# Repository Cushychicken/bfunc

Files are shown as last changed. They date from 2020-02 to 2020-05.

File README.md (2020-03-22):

# bfunc - An open source, breadboard friendly function generator

These are the source files for bfunc, a function generator I've been desiging, building, and programming in my spare time. 

The fastest way to understand what's going on here is to read [the design document](http://cushychicken.github.io/bfunc-design-doc/). That should give you a good top-level understanding of this project. If it doesn't, there's a Contact link on my blog. I encourage you to let me know if there's something you don't understand, or is otherwise unclear!

## Project Structure

All hardware files can be found in the `hardware/` directory. All hardware design was done using KiCAD. 

Software is broken into two directories: 

* `sw_embedded/` for all the code running on the bFunc board, and
* `sw_desktop/`, which contains the Python app for the GUI. 

The sw_embedded directory contains two subfolders:

* `stm32_cube_bfunc/` contains all the software used for building the prototype, which I made out of a STM32 BluePill board and a SparkFun Minigen Pro shield. 
* `bfunc_rev1/` contains all the software used in the first board revision. 

## How can I contribute? 

I'm so glad you asked! Check out the [Call for Users](http://cushychicken.github.io/bfunc-call-for-users/) page on my blog. That will outline the next steps for getting a board, and getting yourself set up to work on it. 

After all that, if you _still_ can't get enough bFunc in your life - I've been keeping weekly project journals on my blog in addition to the design document. Here is a [link to the first one](http://cushychicken.github.io/bfunc-weekone-log/) to get you started.

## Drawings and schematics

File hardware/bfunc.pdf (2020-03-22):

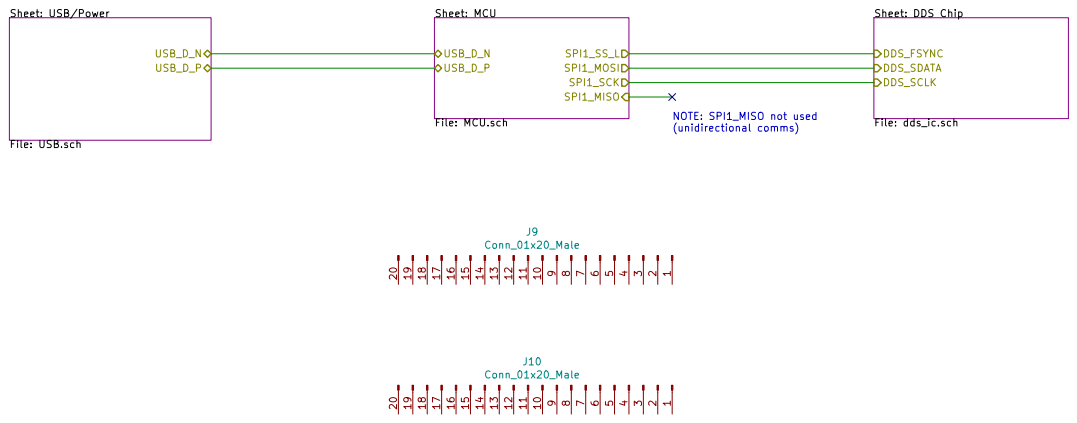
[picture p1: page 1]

Sheet: DDS Chip File: dds_ic.sch DDS_FSYNC

Id: 1/4 Title: File: bfunc.sch Sheet: /

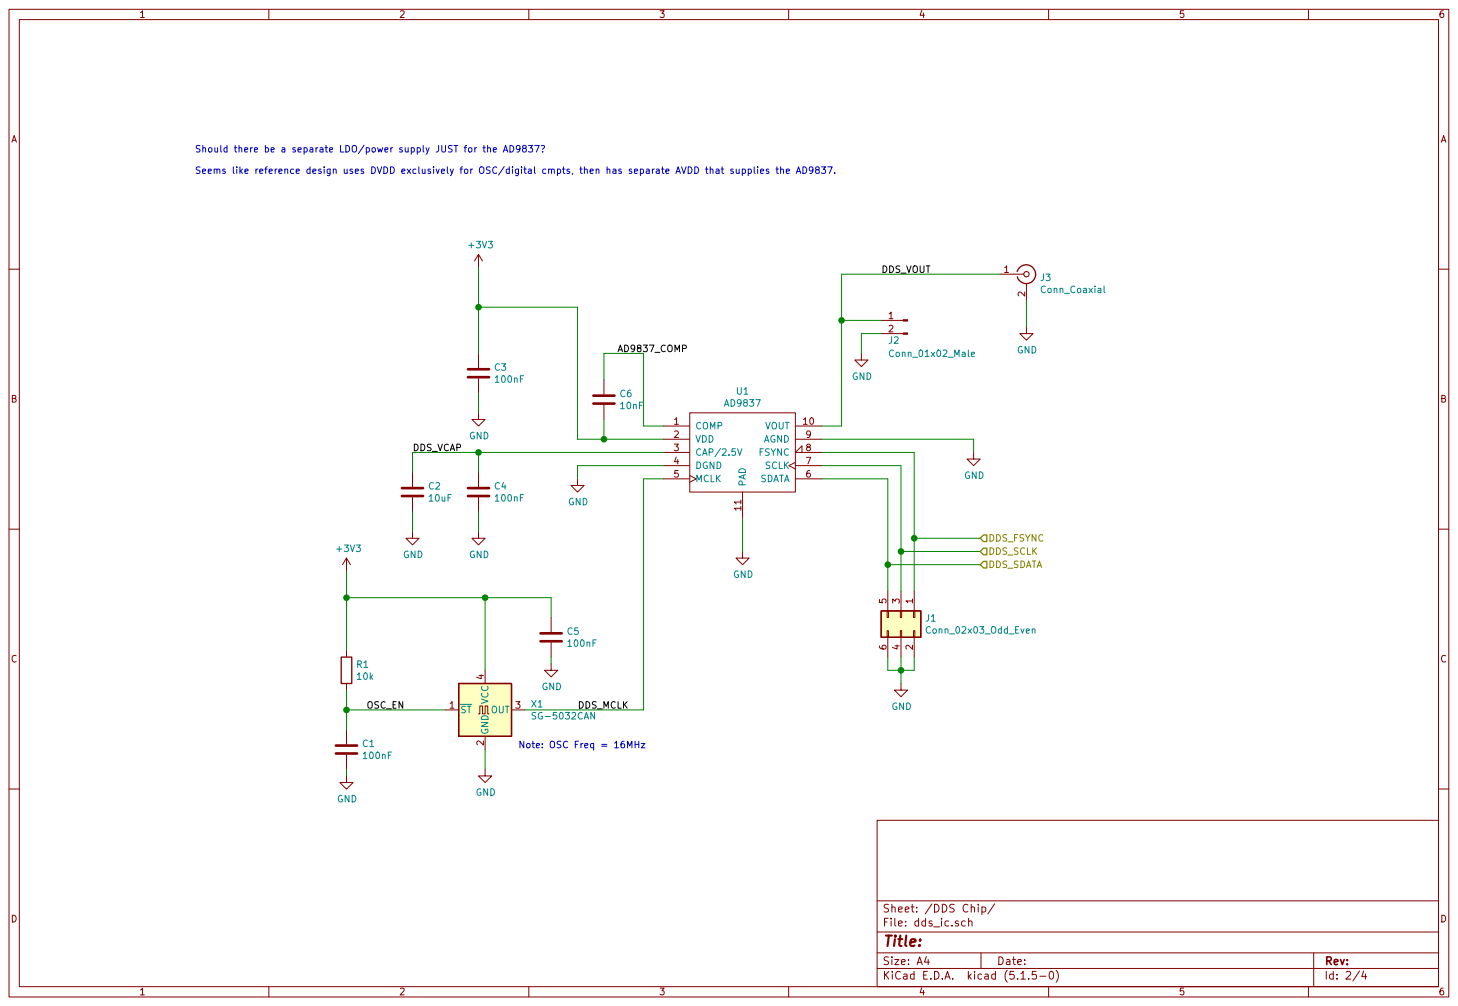
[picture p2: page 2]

Should there be a separate LDO/power supply JUST for the AD9837?

Seems like reference design uses DVDD exclusively for OSC/digital cmpts, then has separate AVDD that supplies the AD9837.

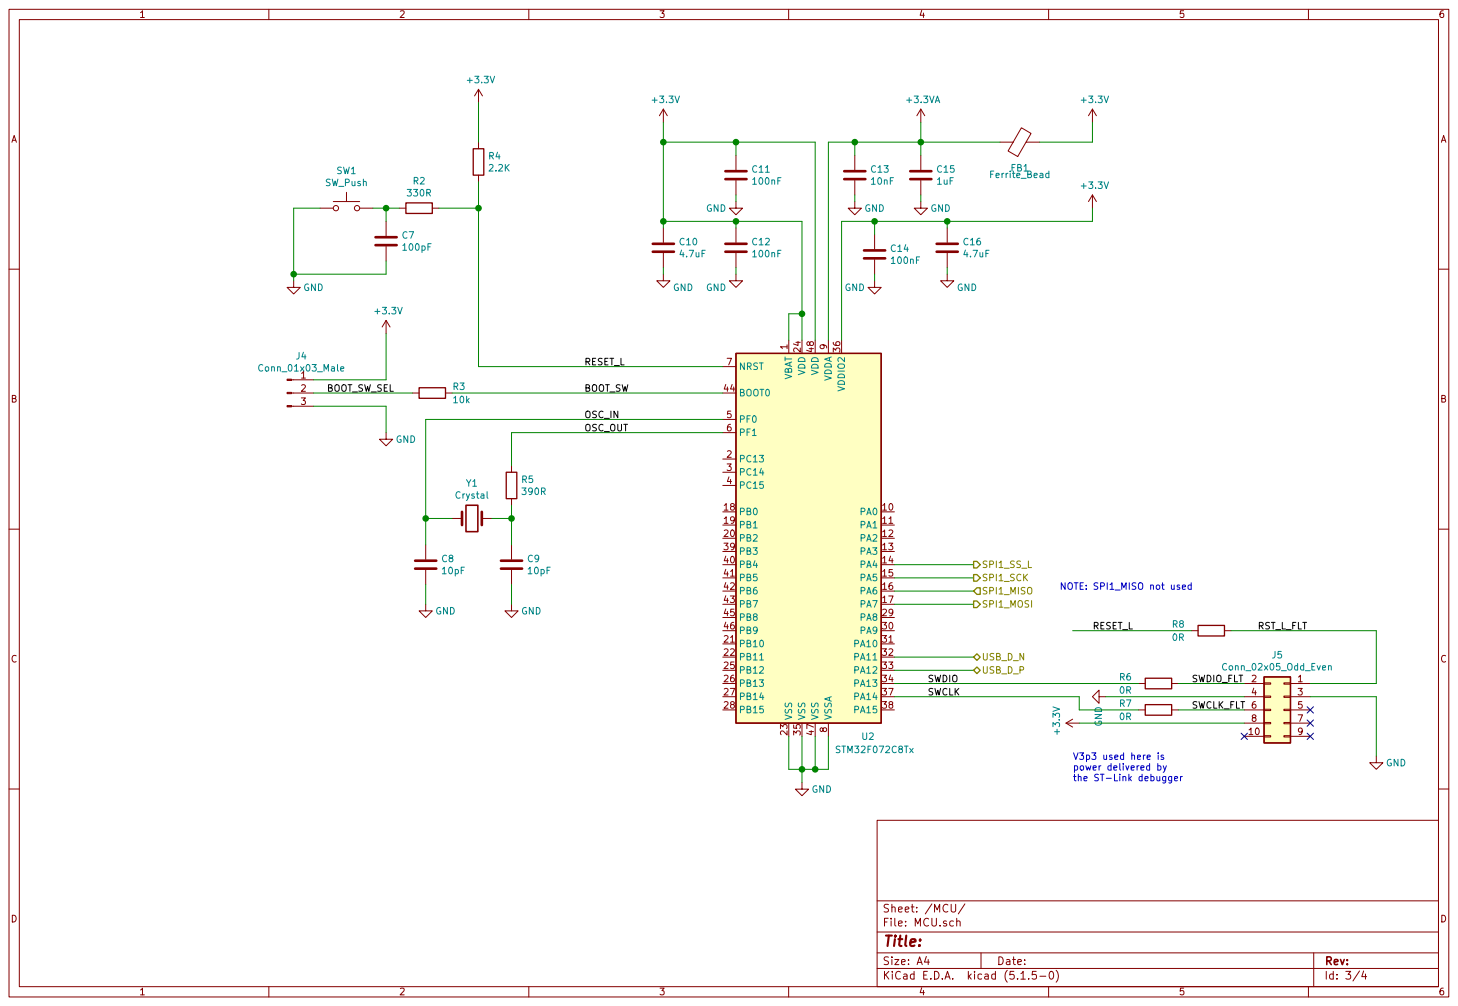
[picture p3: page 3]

1 PA0 10 PA1 11 PA2 12 PA3 13 PA4 14 PA5 15 PA6 16 PA7 17 PB0 18 PB1 19 PC13 2 PB2 20 PB10 21 PB11 22 VSS 23 VDD 24 PB12 25 PB13 26 PB14 27 PB15 28 PA8 29 PC14 3 PA9 30 PA10 31 PA11 32 PA12 33 PA13 34 VSS 35 VDDIO2 36 PA14 37 PA15 38 PB3 39 PC15 4 PB4 40 PB5 41 PB6 42 PB7 43 BOOT0 44 PB8 45 PB9 46 VSS 47 VDD 48 PF0 5 PF1 6 NRST 7 VSSA

power delivered by
the ST-Link debugger

Id: 3/4 Title: File: MCU.sch Sheet: /MCU/

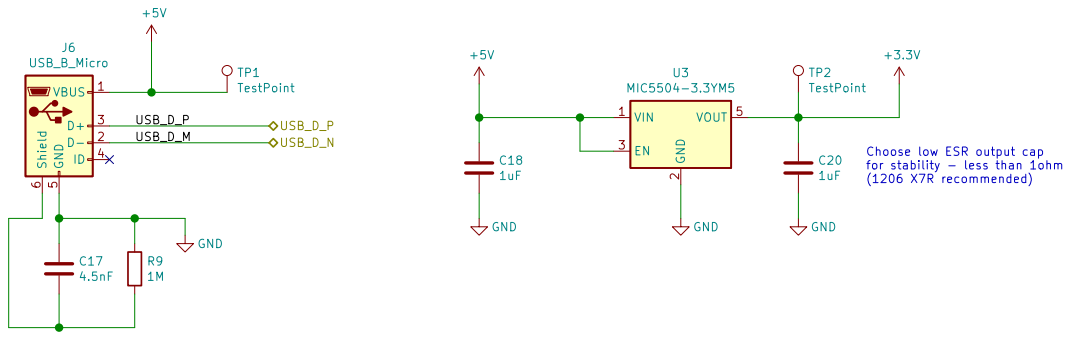
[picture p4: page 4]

2 EN 3 VOUT 5 U3 MIC5504-3.3YM5 TP2 TestPoint TP1 TestPoint GND

Choose low ESR output cap
for stability - less than 1ohm
(1206 X7R recommended)

Id: 4/4 Title: File: USB.sch Sheet: /USB/Power/

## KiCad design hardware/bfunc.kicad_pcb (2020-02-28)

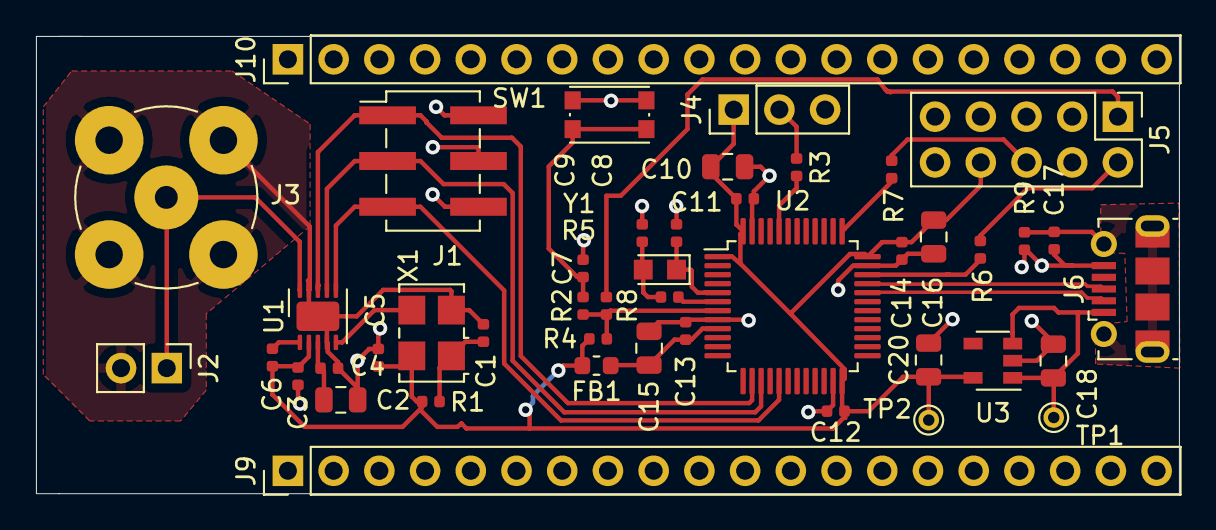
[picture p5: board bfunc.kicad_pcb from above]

Board: 2 copper layers, 63.5 x 25.4 mm, 45 parts (0 on the bottom side), 27 nets.

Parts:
C1, C3, C4, C5, C11, C12, C14: 100nF; C_0402_1005Metric
C2: 10uF; C_0805_2012Metric
C6, C13: 10nF; C_0402_1005Metric
C7: 100pF; C_0402_1005Metric
C8, C9: 10pF; C_0402_1005Metric
C10, C16: 4.7uF; C_0805_2012Metric
C15, C18, C20: 1uF; C_0805_2012Metric
C17: 4.5nF; C_0402_1005Metric
FB1: Ferrite_Bead; L_0603_1608Metric
J1: Conn_02x03_Odd_Even; PinHeader_2x03_P2.54mm_Vertical_SMD
J2: Conn_01x02_Male; PinHeader_1x02_P2.54mm_Vertical
J3: Conn_Coaxial; BNC_TEConnectivity_1478204_Vertical
J4: Conn_01x03_Male; PinHeader_1x03_P2.54mm_Vertical
J5: Conn_02x05_Odd_Even; PinHeader_2x05_P2.54mm_Vertical
J6: USB_B_Micro; USB_Micro-B_Molex-105017-0001
J9, J10: Conn_01x20_Male; PinHeader_1x20_P2.54mm_Vertical
R1, R3: 10k; R_0402_1005Metric
R2: 330R; R_0402_1005Metric
R4: 2.2K; R_0402_1005Metric
R5: 390R; R_0402_1005Metric
R6, R7, R8: 0R; R_0402_1005Metric
R9: 1M; R_0402_1005Metric
SW1: SW_Push; SW_Push_1P1T_NO_CK_KMR2
TP1, TP2: TestPoint; PINTST
U1: AD9837; LFCSP-WD-10-1EP_3x3mm_P0.5mm_EP1.64x2.38mm
U2: STM32F072C8Tx; LQFP-48_7x7mm_P0.5mm
U3: MIC5504-3.3YM5; SOT-23-5
X1: SG-5032CAN; Oscillator_SMD_SeikoEpson_SG8002LB-4pin_5.0x3.2mm
Y1: Crystal; Crystal_SMD_TXC_9HT11-2pin_2.0x1.2mm_HandSoldering

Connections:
+3.3VA: C13.1, C15.1, FB1.1, U2.9
+3V3: C3.1, C5.1, C6.2, C10.1, C11.1, C12.1, C14.1, C16.1, C20.1, FB1.2, J4.1, J5.8, R1.1, R4.1, TP2.1, U1.2, U2.1, U2.24, U2.36, U2.48, U3.5, X1.4
+5V: C18.1, J6.1, TP1.1, U3.1, U3.3
/DDS Chip/AD9837_COMP: C6.1, U1.1
/DDS Chip/DDS_FSYNC: J1.1, U1.8, U2.14
/DDS Chip/DDS_MCLK: U1.5, X1.3
/DDS Chip/DDS_SCLK: J1.3, U1.7, U2.15
/DDS Chip/DDS_SDATA: J1.5, U1.6, U2.17
/DDS Chip/DDS_VCAP: C2.1, C4.1, U1.3
/DDS Chip/DDS_VOUT: J2.1, J3.1, U1.10
/DDS Chip/OSC_EN: C1.1, R1.2, X1.1
/MCU/BOOT_SW: R3.1, U2.44
/MCU/BOOT_SW_SEL: J4.2, R3.2
/MCU/OSC_IN: C8.1, U2.5, Y1.1
/MCU/OSC_OUT: R5.1, U2.6
/MCU/RESET_L: R2.1, R4.2, R8.2, U2.7
/MCU/RST_L_FLT: J5.1, R8.1
/MCU/SWCLK: R7.2, U2.37
/MCU/SWCLK_FLT: J5.6, R7.1
/MCU/SWDIO: R6.2, U2.34
/MCU/SWDIO_FLT: J5.2, R6.1
/MCU/USB_D_N: J6.2, U2.32
/MCU/USB_D_P: J6.3, U2.33
GND: C1.2, C2.2, C3.2, C4.2, C5.2, C7.2, C8.2, C9.2, C10.2, C11.2, C12.2, C13.2, C14.2, C15.2, C16.2, C17.1, C18.2, C20.2, J1.2, J1.4, J1.6, J2.2, J3.2, J4.3, J5.3, J5.4, J6.5, R9.1, SW1.1, U1.4, U1.9, U1.11, U2.8, U2.23, U2.35, U2.47, U3.2, X1.2
unnamed: C7.1, R2.2, SW1.2
unnamed: C9.1, R5.2, Y1.2
unnamed: C17.2, J6.6, R9.2

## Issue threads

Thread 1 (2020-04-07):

Waveform out of sync over 2.3mhz.

whinis, 2020-04-07:
Once the frequency goes above 2.3mhz or there about the signal appear to lose sync for all wave forms. The frequency appears to be close to the set value up to 5mhz but  it fails  to stay consistent. Below are 2 captures from my oscilloscope of a Square wave and Sine wave both at 3mhz
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

Cushychicken, 2020-04-07:
@whinis have you tried increasing the vertical scale of your oscilloscope? I noticed a similar problem with my Rigol not triggering properly at lower amplitudes. Increasing the vertical signal scale resolved that.

I see an issue with the sine wave, but a different one - at 2.3MHz (and to a lesser extent at 1MHz) you're seeing extra harmonic junk from the DDS DAC. Instead of being a nice smooth sine wave, you get a bunch of nasty capacitive transitions. Will need to design a filter for the next board rev to improve this.

I see the issue you describe with the square wave. That's junk. Need to dig into that.

whinis, 2020-04-07:
Yes, I have attempted to increase the vertical scale and see the same stuff. Its likely the harmonics and them switching forms back and forth that's causing this issue because as you can sort of see there is 3 nodes in the sine wave.

whinis, 2020-04-08:
Here is an update. I tried it with both a 100nf capacitor as suggested in the datasheet as well as 100pf. the 100pf helped a bit but there is other errors happening. Here it is now at 5mhz, both an average as well as single shot. The 100nf turned the square into a triangle and ruined both sine and triangle waves.
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

Cushychicken, 2020-04-09:
Interesting. Just to confirm - you're placing this capacitor at the output, from the VOUT pin to AGND? I haven't seen any references to needing a 100nF cap at the VOUT pin in the datasheet. There is the test circuit suggestion of adding 20pF at the output pin on page 9 of the datasheet:

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

This is also consistent with the AD9834, which suggests including a 20pF cap at the current output of that chip to help reduce clock feedthru. (The AD9837 integrates a 200 ohm termination resistor onto the die - these are external components required by the AD9834.)

In any case - what I think we're seeing here is harmonic overtones as a result of operating closer to the DDS chip's oscillator frequency. The on-board oscillator is running at 16MHz - it's definitely not going to do anything close to sinusoidal reconstruction as you get closer to 8MHz.

A higher order filter design is needed, and that's probably not something we'll be able to add to this PCB. Might be a good job for a separate filter PCB, though. I've linked this circuit note from Analog Devices on the AD9834, which is a part in the same family as the AD9837, which includes a little design brief for a 7th order elliptic lowpass filter at the output of the generator. You can see the spectrum plots on page 3 that shows the difference in harmonic content between the raw IOUT terminated output (equivalent to VOUT in our case) and the harmonic content at the output of the elliptic filter.

https://www.analog.com/media/en/reference-design-documentation/reference-designs/CN0304.pdf

whinis, 2020-04-09:
So, I found that cap advice on their evaluation board at https://www.analog.com/media/en/technical-documentation/user-guides/UG-269.pdf
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

However yes, this is a 0603 cap sitting between the VOUT and AGND pins directly on the other side of the board from the BNC. its the perfect distance for a 0603

Cushychicken, 2020-04-09:
Hm. I wonder if that was a placeholder footprint. (200Ω || 100nF) yields a -3dB frequency of about 8kHz.

whinis, 2020-04-09:
If the picture on your website is correct you may be onto something as that pad looks unpopulated on the image.
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

Cushychicken, 2020-04-11:
@whinis have you ever tried your hand at filter design before? I plugged in the parameters for a 7th order elliptic lowpass filter into the [rf-tools filter calculator website](https://rf-tools.com/lc-filter/) and got this result:

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

I don't have any of the components for this on hand - wondering if you happen to have any of the required inductor or cap values.

whinis, 2020-04-11:
I don't have the inductors on hand but every everything else. Also need to wait until the end of the month to order anything else.

Cushychicken, 2020-04-12:
Some good app notes on jitter/sync issues for output. Sounds like a filter will help.

https://www.analog.com/media/en/technical-documentation/application-notes/351016224AN_837.pdf?doc=AD9834.pdf

https://www.analog.com/media/en/technical-documentation/application-notes/475354741144165304775709740692131461831AN823_0.pdf

whinis, 2020-05-16:
Alright I finally got parts in and have an update. For the square wave latest that filter really helps and allows for an ultra clean square wave up to about 4 mhz( tested from around 10k-5mhz). After 4 mhz I seem to get some extreme issues on the wave form and I end up getting only half the designate frequency with lots of harmonics.

Cushychicken, 2020-05-17:
Cool! Can you post a picture of the waveform with the harmonics?

There are some tradeoffs of elliptic filters and funky group delay is one of them. Might have to modify topology slightly to a Bessel filter which is not a huge reorganization from elliptic.

whinis, 2020-05-17:
Square wave at 4 mhz
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
Square wave at 4.2Mhz
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
Sine wave at 100Khz
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
Triangle at 100Khz
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

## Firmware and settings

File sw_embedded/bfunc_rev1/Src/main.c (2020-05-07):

/**
  ******************************************************************************
  * @file           : main.c
  * @brief          : Main program body
  ******************************************************************************
  * This notice applies to any and all portions of this file
  * that are not between comment pairs USER CODE BEGIN and
  * USER CODE END. Other portions of this file, whether 
  * inserted by the user or by software development tools
  * are owned by their respective copyright owners.
  *
  * Copyright (c) 2020 STMicroelectronics International N.V. 
  * All rights reserved.
  *
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
  ******************************************************************************
  */
/* Includes ------------------------------------------------------------------*/
#include "main.h"
#include "stm32f0xx_hal.h"
#include "usb_device.h"

/* USER CODE BEGIN Includes */
#include "usbd_cdc_if.h"
#include <string.h>


#define SYSMEM_RESET_VECTOR            0x1fffC804
#define RESET_TO_BOOTLOADER_MAGIC_CODE 0xDEADBEEF
#define BOOTLOADER_STACK_POINTER       0x200014a8
/* USER CODE END Includes */

SPI_HandleTypeDef hspi1;

TIM_HandleTypeDef htim2;

/* USER CODE BEGIN PV */

enum states {
    IDLE,
    WFM_OUT_SINE,
    WFM_OUT_TRIANGLE,
    WFM_OUT_SQUARE,
    WFM_OUT_SAWTOOTH,
    MOD_PSK
};

enum waveform_modes {
    SINE,
    TRIANGLE,
    SQUARE,
    SAWTOOTH
};

struct ad9837_ctrl_reg {
    unsigned int reserved0  : 1;
    unsigned int mode       : 1;
    unsigned int reserved2  : 1;
    unsigned int div2       : 1;
    unsigned int reserved4  : 1;
    unsigned int opbiten    : 1;
    unsigned int sleep12    : 1;
    unsigned int sleep1     : 1;
    unsigned int reset      : 1;
    unsigned int reserved9  : 1;
    unsigned int psel       : 1;
    unsigned int fsel       : 1;
    unsigned int hlb        : 1;
    unsigned int b28        : 1;
    unsigned int freqreg    : 2;
};

struct ad9837_freq_reg {
    unsigned int freqset    : 14;
    unsigned int freqreg    : 2;
};

struct ad9837_phase_reg {
    unsigned int phaseset   : 12;
    unsigned int reserved   : 1;
    unsigned int phasereg   : 3;
};

union ad9837_dds_ctrl {
    struct ad9837_ctrl_reg reg;
    uint8_t data[2];
};

union ad9837_freq_set {
    struct ad9837_freq_reg reg;
    uint8_t data[2];
};

union ad9837_phase_set {
    struct ad9837_phase_reg reg;
    uint8_t data[2];
};

typedef struct {
	uint32_t namesz;
	uint32_t descsz;
	uint32_t type;
	uint8_t data[];	
} ElfNoteSection_t;

extern const ElfNoteSection_t g_note_build_id;

extern uint32_t dfu_reset_to_bootloader_magic;

/* USER CODE END PV */

void SystemClock_Config(void);
static void MX_GPIO_Init(void);
static void MX_SPI1_Init(void);
static void MX_TIM2_Init(void);

/* USER CODE BEGIN PFP */
void InitCtrlAD9837(union ad9837_dds_ctrl *dds_control);
void StartOutput(union ad9837_dds_ctrl *dds_control);
void StopOutput(union ad9837_dds_ctrl *dds_control);
void SetFreq0Value(uint32_t freq);
void SetFreq1Value(uint32_t freq);
void SetPhase0Value(uint16_t phase);
void SetPhase1Value(uint16_t phase);
void SetWaveformMode(enum   states          current_state,
				 	 union  ad9837_dds_ctrl *dds_control);
void ToggleFreqReg(union  ad9837_dds_ctrl *dds_control);
void TogglePhaseReg(union  ad9837_dds_ctrl *dds_control);
void SetSymbolRate(TIM_TypeDef *TIMx, uint16_t ms);
void StopModulation(TIM_TypeDef *TIMx);

enum states NextState(	enum states CurrentState);
void ProcessCommand(	uint8_t *cmd_buffer, 
						union ad9837_dds_ctrl *dds_control);

/* USER CODE END PFP */

/* USER CODE BEGIN 0 */

// Resets the chip in System Memory Bootloader mode
void dfu_run_bootloader()
{
    dfu_reset_to_bootloader_magic = RESET_TO_BOOTLOADER_MAGIC_CODE;
    NVIC_SystemReset();
}
/* USER CODE END 0 */

/**
  * @brief  The application entry point.
  *
  * @retval None
  */
int main(void)
{
  /* MCU Configuration----------------------------------------------------------*/

  /* Reset of all peripherals, Initializes the Flash interface and the Systick. */
  HAL_Init();

  /* Configure the system clock */
  SystemClock_Config();

  /* Initialize all configured peripherals */
  MX_GPIO_Init();
  MX_SPI1_Init();
  MX_USB_DEVICE_Init();
  MX_TIM2_Init();
  /* USER CODE BEGIN 2 */
  // Following line included to enable SWD debug
  //AFIO->MAPR = AFIO_MAPR_SWJ_CFG_JTAGDISABLE; 

  union ad9837_dds_ctrl dds_control;

  // Initializing AD9837 as per ADI App Note AN-1070
  InitCtrlAD9837(&dds_control);
  StopOutput(&dds_control);
  SetFreq0Value(0x00000000);
  SetFreq1Value(0x00000000);
  SetPhase0Value(0x0000);
  SetPhase1Value(0x0000);


  uint8_t cmd_buffer[64];
  uint8_t cmd_buffer_index = 0;
  uint8_t rcv_buffer_index = 0;
  uint8_t result;

  char c;
  extern volatile uint8_t   usb_packet_flag;

  //Initialize cmd_buffer
  for (c = 0; c < 64; c++) {
	  cmd_buffer[(uint8_t)c] = 0;
  }
  c = '\0';

  //HAL_TIM_Base_Start_IT(&htim2); 
  /* USER CODE END 2 */

  /* Infinite loop */
  /* USER CODE BEGIN WHILE */
  while (1)
  {
	// Start-of-superloop blinky 
	//GPIOC->BSRR = GPIO_BSRR_BS_13;

	// Main Serial Buffer Input Loop
	//  Loops thru UserRxBufferFS, copies char into buffer, 
	//  nulls out the same char in UserRxBufferFS
    if (usb_packet_flag) {
		rcv_buffer_index = 0;
		while ( UserRxBufferFS[rcv_buffer_index] != '\0' ) {
			c = UserRxBufferFS[rcv_buffer_index];
			UserRxBufferFS[rcv_buffer_index] = '\0';

			switch (c) 
			{
				case '\b':	// Backspace
					if (cmd_buffer_index > 0) {
						cmd_buffer[--cmd_buffer_index] = '\0';
						result = CDC_Transmit_FS((uint8_t *)" \b", 2);
						while (result == USBD_BUSY) {
							result = CDC_Transmit_FS((uint8_t *)" \b", 2);
						}
					}
					break;
	    	
				case 0x7f:	// Backspace, on a Mac
					if (cmd_buffer_index > 0) {
						cmd_buffer[--cmd_buffer_index] = '\0';
						result = CDC_Transmit_FS((uint8_t *)"\b \b", 3);
						while (result == USBD_BUSY) {
							result = CDC_Transmit_FS((uint8_t *)"\b \b", 3);
						}
					}
					break;
	    	
				case '\n':	// Newline
					ProcessCommand(cmd_buffer, &dds_control);
					cmd_buffer_index = 0;
					cmd_buffer[cmd_buffer_index] = '\0';
					break;

				case '\r':	// Carriage return
					ProcessCommand(cmd_buffer, &dds_control);
					cmd_buffer_index = 0;
					cmd_buffer[cmd_buffer_index] = '\0';
					break;
	    	
				default:	// any other char; appends char to buffer
					cmd_buffer[cmd_buffer_index++] = c;
					cmd_buffer[cmd_buffer_index] = '\0';
					break;
			}
			rcv_buffer_index++;
		}
		usb_packet_flag = 0;
	}

  /* USER CODE END WHILE */

  /* USER CODE BEGIN 3 */
  }
  /* USER CODE END 3 */

}

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
/* USER CODE BEGIN 4 */

// Initializes all the values of the DDS Control register
//  to a known state. 
void InitCtrlAD9837(union ad9837_dds_ctrl *dds_control)
{
    dds_control->reg.freqreg    = 0;
    dds_control->reg.b28        = 1;
    dds_control->reg.hlb        = 0;
    dds_control->reg.fsel       = 0;
    dds_control->reg.psel       = 0;
    dds_control->reg.reserved9  = 0;
    dds_control->reg.reset      = 1;
    dds_control->reg.sleep1     = 0;
    dds_control->reg.sleep12    = 0;
    dds_control->reg.opbiten    = 0;
    dds_control->reg.reserved4  = 0;
    dds_control->reg.div2       = 0;
    dds_control->reg.reserved2  = 0;
    dds_control->reg.mode       = 0;
    dds_control->reg.reserved0  = 0;
}

// Sets the value of Freq0 frequency register
void SetFreq0Value(uint32_t freq)
{
    union ad9837_freq_set freq0;

    // Note: All SPI transactions are len=1, but 
    // require a 2 byte input due to the peripheral being 
    // in 16-bit output mode
   
    // Sets 14 LSBs of Freq0 register
    freq0.reg.freqreg = 1;
    freq0.reg.freqset = (unsigned int)(freq & 0x00003fff);
    HAL_SPI_Transmit(&hspi1, freq0.data, 1, 10);
    // Sets 14 MSBs of Freq0 register
    freq0.reg.freqreg = 1;
    freq0.reg.freqset = (unsigned int)((freq & 0x0fffc000) >> 14);
    HAL_SPI_Transmit(&hspi1, freq0.data, 1, 10);
}

// Sets the value of Freq1 frequency register
void SetFreq1Value(uint32_t freq)
{
    union ad9837_freq_set freq1;
    
    // Note: All SPI transactions are len=1, but 
    // require a 2 byte input due to the peripheral being 
    // in 16-bit output mode
   
	// Sets 14 LSBs of Freq1 register
    freq1.reg.freqreg = 2;
    freq1.reg.freqset = (unsigned int)(freq & 0x00003fff);
    HAL_SPI_Transmit(&hspi1, freq1.data, 1, 10);
    
	// Sets 14 MSBs of Freq1 register
    freq1.reg.freqreg = 2;
    freq1.reg.freqset = (unsigned int)((freq & 0x0fffc000) >> 14);
    HAL_SPI_Transmit(&hspi1, freq1.data, 1, 10);
}

// Sets the value of Phase0 phase register
void SetPhase0Value(uint16_t phase)
{
    union ad9837_phase_set phase0;
    phase0.reg.phasereg = 6; // Must be 0x6 (0b110) to set PHASEREG bit
    phase0.reg.reserved = 0;
    phase0.reg.phaseset = (phase & 0x0fff);
    HAL_SPI_Transmit(&hspi1, phase0.data, 1, 10);
}

// Sets the value of Phase1 phase register
void SetPhase1Value(uint16_t phase)
{
    union ad9837_phase_set phase1;
    phase1.reg.phasereg = 7; // Must be 0x7 (0b111) to set PHASEREG bit
    phase1.reg.reserved = 0;
    phase1.reg.phaseset = (phase & 0x0fff);
    HAL_SPI_Transmit(&hspi1, phase1.data, 1, 10);
}

// Starts the output of the DDS chip 
void StartOutput(union ad9837_dds_ctrl *dds_control) {
    // Note: All SPI transactions are len=1, but 
    // require a 2 byte input due to the peripheral being 
    // in 16-bit output mode
    dds_control->reg.reset	 = 0;
    //dds_control->reg.sleep12 = 0;
    HAL_SPI_Transmit(&hspi1,
                     dds_control->data, 1, 10);
}

// Stops the output of the DDS chip 
void StopOutput(union ad9837_dds_ctrl *dds_control)
{
    // Note: All SPI transactions are len=1, but 
    // require a 2 byte input due to the peripheral being 
    // in 16-bit output mode
    dds_control->reg.reset   = 1;
    //dds_control->reg.sleep12 = 1;
    HAL_SPI_Transmit(&hspi1,
                     dds_control->data, 1, 10);
}

// Sets the output waveform mode of the DDS chip
void SetWaveformMode(enum   states          current_state,
                     union  ad9837_dds_ctrl *dds_control)
{
    switch (current_state) {
        case WFM_OUT_SINE:
            // Clears OPBITEN and MODE bits
            dds_control->reg.opbiten = 0;
            dds_control->reg.mode    = 0;
            // Transmits new settings to DDS via SPI
            HAL_SPI_Transmit(&hspi1,
                             dds_control->data,
                             1,
                             10);
			StartOutput(dds_control);
            break;
        case WFM_OUT_TRIANGLE:
            // Sets MODE bit; clears OPBITEN
            dds_control->reg.opbiten = 0;
            dds_control->reg.mode    = 1;
            // Transmits new settings to DDS via SPI
            HAL_SPI_Transmit(&hspi1,
                             dds_control->data,
                             1,
                             10);
			StartOutput(dds_control);
            break;
        case WFM_OUT_SAWTOOTH:
			// Note - this is same output setting as TRIANGLE

            // Sets MODE bit; clears OPBITEN
            dds_control->reg.opbiten = 0;
            dds_control->reg.mode    = 1;
            // Transmits new settings to DDS via SPI
            HAL_SPI_Transmit(&hspi1,
                             dds_control->data,
                             1,
                             10);
			StartOutput(dds_control);
			break;
        case WFM_OUT_SQUARE:
            // Sets OPBITEN;
            dds_control->reg.opbiten = 1;
            dds_control->reg.mode    = 0;
            dds_control->reg.div2    = 1;
            // Transmits new settings to DDS via SPI
            HAL_SPI_Transmit(&hspi1,
                             dds_control->data,
                             1,
                             10);
			StartOutput(dds_control);
            break;
        case MOD_PSK:
            // Clears OPBITEN and MODE bits
            dds_control->reg.opbiten = 0;
            dds_control->reg.mode    = 0;
            // Transmits new settings to DDS via SPI
            HAL_SPI_Transmit(&hspi1,
                             dds_control->data,
                             1,
                             10);
            // Set timer with modulation interval
            // Start waveform output
            break;
		case IDLE:
			StopOutput(dds_control);
            StopModulation(TIM2);
			break;
        default:
	        break;
    }
}

// Sets modulation keying interval of modulation states
void SetSymbolRate(TIM_TypeDef *TIMx, uint16_t ms) {
    TIMx->CR1 &= ~(TIM_CR1_CEN); 

    if (TIMx == TIM2) {
        RCC->APB1RSTR |= (RCC_APB1RSTR_TIM2RST);
        RCC->APB1RSTR &= ~(RCC_APB1RSTR_TIM2RST);
    }

    TIMx->PSC = 48000000/1000;
    TIMx->ARR = ms;

    TIMx->EGR  |= TIM_EGR_UG; 
    TIMx->DIER |= TIM_DIER_UIE; 
    TIMx->CR1  |= TIM_CR1_CEN; 
}

// Stops timer that toggles modulations
void StopModulation(TIM_TypeDef *TIMx) {
    TIMx->CR1 &= ~(TIM_CR1_CEN);
}

// Swaps between freq registers used for output
void ToggleFreqReg(union  ad9837_dds_ctrl *dds_control)
{
    if (dds_control->reg.fsel == 1) {
        dds_control->reg.fsel = 0;
    } else {
        dds_control->reg.fsel = 1;
    }

    HAL_SPI_Transmit(&hspi1,
                     dds_control->data,
                     1,
                     10);
}

// Swaps between phase registers used for output
void TogglePhaseReg(union  ad9837_dds_ctrl *dds_control)
{
    static uint8_t phaseout = 0;

    if (phaseout == 0) {
        phaseout = 1;
        dds_control->reg.psel = 1;
    } else {
        phaseout = 0;
        dds_control->reg.psel = 0;
    }

    HAL_SPI_Transmit(&hspi1,
                     dds_control->data,
                     1,
                     10);
}


// Helper function that just cycles through the states 
// available to the waveform generator
enum states NextState(enum states CurrentState)
{
    switch (CurrentState) {
        case IDLE:
            return WFM_OUT_SINE;
            break;
        case WFM_OUT_SINE:
            return WFM_OUT_TRIANGLE;
            break;
        case WFM_OUT_TRIANGLE:
            return WFM_OUT_SQUARE;
            break;
        case WFM_OUT_SQUARE:
            return IDLE;
            break;
        default:
            return IDLE;
            break;
    }
}

// Parsing function that takes buffered command input 
//  and generates the proper interpreted behavior for 
//  the bFunc board. 
//
//  Responsible for both command parsing and setting 
//  frequency/phase register values. 
void ProcessCommand(uint8_t *cmd_buffer, 
					union ad9837_dds_ctrl *dds_control) 
{
	char delim = ' ';
	uint8_t position = 0;
	uint8_t *parms[10];

	uint8_t result;
	uint8_t length;
	
	uint32_t frequency;
	uint16_t phase;

	// Zero parameter array
	for (position = 0; position < 10; position++) {
		parms[position] = 0;
	}

	// Split all params by delimiter; adds NULL to final position
	position = 0;
	uint8_t *ptr_split = (uint8_t *)strtok((char *)cmd_buffer, &delim);
	while (ptr_split != NULL) {
		parms[position] = ptr_split;
		ptr_split = (uint8_t *)strtok(NULL, &delim);
		position++;
	}
	parms[position] = NULL;
	position = 0;

	// Prints a newline so it's separate from cmd buffer
	result = CDC_Transmit_FS((uint8_t *)"\n\r", 2);
	while (result == USBD_BUSY) {
		result = CDC_Transmit_FS((uint8_t *)"\n\r", 2);
	}

	// Prints the contents of the parms array
	while (parms[position] != NULL) {
		length = strlen((char *)parms[position]);
		result = CDC_Transmit_FS(parms[position], length);
		while (result == USBD_BUSY) {
			result = CDC_Transmit_FS(parms[position], length);
		}

		// Prints a newline so it's separate from cmd buffer
		result = CDC_Transmit_FS((uint8_t *)"\n\r", 2);
		while (result == USBD_BUSY) {
			result = CDC_Transmit_FS((uint8_t *)"\n\r", 2);
		}

		position++;
	}

	// This is where the command parsing happens
	if ( (strcmp((char *)parms[0], "sine")		== 0) )
	{
		// use atoi(parms[1]) as frequency
		// Is not called if there is no parms[1]
		if (position > 1) {
			frequency = (uint32_t)(16.777216 * (float)atoi((char *)parms[1]));
			SetFreq0Value(frequency);
		}

		// use atoi(parms[2]) as phase
		// Is not called if there is no parms[2]
		if (position > 2) {
			phase = (uint16_t)(11.377774 * (float)atoi((char *)parms[2]));
			SetPhase0Value(phase);
		}
	
		// Sets waveform state, starts DDS output 
		SetWaveformMode(WFM_OUT_SINE, dds_control);
	} 
	else if ((strcmp((char *)parms[0], "triangle")	== 0) )
	{
		// use atoi(parms[1]) as frequency
		// Is not called if there is no parms[1]
		if (position > 1) {
			frequency = (uint32_t)(16.777216 * (float)atoi((char *)parms[1]));
			SetFreq0Value(frequency);
		}

		// use atoi(parms[2]) as phase
		// Is not called if there is no parms[2]
		if (position > 2) {
			phase = (uint16_t)(11.377774 * (float)atoi((char *)parms[2]));
			SetPhase0Value(phase);
		}
	
		// Sets waveform state, starts DDS output 
		SetWaveformMode(WFM_OUT_TRIANGLE, dds_control);
	}
	else if ((strcmp((char *)parms[0], "square")	== 0) )
	{
		// use atoi(parms[1]) as frequency
		// Is not called if there is no parms[1]
		if (position > 1) {
			frequency = (uint32_t)(16.777216 * (float)atoi((char *)parms[1]));
			SetFreq0Value(frequency);
		}

		// use atoi(parms[2]) as phase
		// Is not called if there is no parms[2]
		if (position > 2) {
			phase = (uint16_t)(11.377774 * (float)atoi((char *)parms[2]));
			SetPhase0Value(phase);
		}
	
		// Sets waveform state, starts DDS output 
		SetWaveformMode(WFM_OUT_SQUARE, dds_control);
	}
	else if ((strcmp((char *)parms[0], "sawtooth")	== 0) )
	{
		// use atoi(parms[1]) as frequency
		// Is not called if there is no parms[1]
		if (position > 1) {
			frequency = (uint32_t)(16.777216 * (float)atoi((char *)parms[1]));
			frequency = (uint32_t)((float)frequency / 2.0); // Needed to get freq down a step	
			SetFreq0Value(frequency);
			SetFreq1Value(frequency);
		}

		// use atoi(parms[2]) as phase
		// Is not called if there is no parms[2]
		if (position > 2) {
			phase = (uint16_t)((float)atoi((char *)parms[2]) + 270.0);
			phase = (uint16_t)(11.377774 * (float)phase);
			SetPhase0Value(phase);
			phase = (uint16_t)((float)atoi((char *)parms[2]) + 90.0);
			phase = (uint16_t)(11.377774 * (float)phase);
			SetPhase1Value(phase);
		} else {
			phase = (uint16_t)(11.377774 * 270.0);
			SetPhase0Value(phase);
			phase = (uint16_t)(11.377774 * 90.0);
			SetPhase1Value(phase);
		}
	
		// Sets waveform state, starts DDS output 
		SetWaveformMode(WFM_OUT_SAWTOOTH, dds_control);
	}
	else if (	(strcmp((char *)parms[0], "freq0")	== 0) )
	{
		// use atoi(parms[1]) as freq0 setting
		// multiplying by 17 gets to freq needed by AD9837 FREQREG
		if (position > 1) {
			frequency = (uint32_t)(16.777216 * (float)atoi((char *)parms[1]));
			SetFreq0Value(frequency);
		}
	}
	else if (	(strcmp((char *)parms[0], "freq1")	== 0) )
	{
		// use atoi(parms[1]) as freq1 setting
		// multiplying by 17 gets to freq needed by AD9837 FREQREG
		if (position > 1) {
			frequency = (uint32_t)(16.777216 * (float)atoi((char *)parms[1]));
			SetFreq1Value(frequency);
		}
	}
	else if (	(strcmp((char *)parms[0], "phase0")	== 0) )
	{
		// use atoi(parms[1]) as phase0 setting
		if (position > 1) {
			phase = (uint16_t)(11.377774 * (float)atoi((char *)parms[1]));
			SetPhase0Value(phase);
		}
	}
	else if (	(strcmp((char *)parms[0], "phase1")	== 0) )
	{
		// use atoi(parms[1]) as phase1 setting
		if (position > 1) {
			phase = (uint16_t)(11.377774 * (float)atoi((char *)parms[1]));
			SetPhase1Value(phase);
		}
	}
	else if ( (strcmp((char *)parms[0], "freqsel")	== 0) ) {
		// Changes freq output register
        ToggleFreqReg(dds_control);
	}
	else if ( (strcmp((char *)parms[0], "phasesel")	== 0) ) {
		// Changes freq output register
        TogglePhaseReg(dds_control);
	}
	else if ( (strcmp((char *)parms[0], "mod_bpsk")	== 0) ) {
		// Sets up bFunc to transmit binary phase shift keying modulation
		if (position > 1) {
			frequency = (uint32_t)(16.777216 * (float)atoi((char *)parms[1]));
			SetFreq0Value(frequency);
			SetFreq1Value(frequency);
		} 

        SetPhase0Value(0);
		phase = (uint16_t)(11.377774 * (float)180.0);
        SetPhase1Value(phase);

        if (position > 2) {
            SetSymbolRate(TIM2, atoi((char *)parms[2]));
        }
		SetWaveformMode(MOD_PSK, dds_control);
	}
	else if ( (strcmp((char *)parms[0], "idle")	== 0) ) {
		// stop output
		SetWaveformMode(IDLE, dds_control);
	}
	else if ( (strcmp((char *)parms[0], "buildid")	== 0) ) {
		// stop output
		const uint8_t *build_id_data = &g_note_build_id.data[g_note_build_id.namesz];

	    result = CDC_Transmit_FS((uint8_t *) "Build ID: ", 10);
	    while (result == USBD_BUSY) {
	        result = CDC_Transmit_FS((uint8_t *) "Build ID: ", 10);
	    }

		for (int i = 0; i < g_note_build_id.descsz; ++i) {
			char buildchar[3];
			sprintf(buildchar, "%02x", build_id_data[i]);
			result = CDC_Transmit_FS((uint8_t *)(buildchar), 2);
			while (result == USBD_BUSY) {
			     result = CDC_Transmit_FS((uint8_t *)(buildchar), 2);
			}
		}

	    result = CDC_Transmit_FS((uint8_t *) "\n\r", 2);
	    while (result == USBD_BUSY) {
	        result = CDC_Transmit_FS((uint8_t *) "\n\r", 2);
	    }

	}
	else if ( (strcmp((char *)parms[0], "upgrade")	== 0) ) {
		dfu_run_bootloader();
	}

	// Transmits shell prompt
	result = CDC_Transmit_FS((uint8_t *) "$> ", 3);
	while (result == USBD_BUSY) {
		result = CDC_Transmit_FS((uint8_t *) "$> ", 3);
	}
}

/* USER CODE END 4 */
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


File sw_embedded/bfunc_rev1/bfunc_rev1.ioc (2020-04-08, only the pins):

Mcu.UserName=STM32F072C8Tx
PA11.Signal=USB_DM
PA12.Signal=USB_DP
PA13.Signal=SYS_SWDIO
PA14.Signal=SYS_SWCLK
PA4.Signal=SPI1_NSS
PA5.Signal=SPI1_SCK
PA6.Signal=SPI1_MISO
PA7.Signal=SPI1_MOSI
PC13.GPIO_Label=GRN_LED
PC13.Signal=GPIO_Output

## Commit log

2020-01-30 bFunc: initial commit
    [bfunc.kicad_pcb, bfunc.sch]
2020-02-04 Broke cmpts into hierarchical design; swapped over to STM32 MCU (better USB reference examples, better toolchain support for my shitty old Mac)
    [MCU.sch, USB.sch, bfunc.sch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]
2020-02-21 Uploaded STM32 configs, plus source code I'm working on for main.c
    [MCU.sch, USB.sch, bfunc.kicad_pcb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]
2020-02-21 Moved all Kicad stuff to /hardware/ directory
    [MCU.sch, USB.sch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]
2020-02-25 Deleted file hardware/bfunc_layout.kicad_pcb; it was a scratch layout that wasn't in use.
    [bfunc_layout.kicad_pcb]
2020-02-28 Minor updates on PCB reviewed for re-fab at CircuitHub
    [bfunc.kicad_pcb]
2020-03-03 Basic USB functionality added - compiles and builds into a machine that switches between waveforms and also does USB loopback over virtual com port
2020-03-03 Bill of Materials for bFunc added in TSV format
    [bfunc_bom.tsv]
2020-03-06 Started new port of code to STM32F072 MCU in bfunc_rev1/ directory; also implemented output selection based on CDC buffer contents
2020-03-17 Added some more buttons and fields to the desktop application (push lags the actual work by a few days)
2020-03-22 Added PDF schematic to the hardware directory
2020-03-23 Added radiobuttons for selectingbetween waveform output or modulation output (modulation is still in development); refactored the link between button helper functions and buttons to no longer use the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
    [app.py]
2020-03-25 Updating KiCAD project file - had some slight updates after adding a PDF schematic
2020-03-27 Updated USB Product String to a custom one that says device is a bFunc
2020-03-27 Plumbed in freq0, freq1, phase0, phase1 settings behind the Tkinter buttons
2020-03-28 Fixed multiplying factors for frequency and phase settings
    [main.c]
2020-04-02 Added STCubeMX codegen bracket comments back - needed for quick peripheral inits while not trashing prewritten code
2020-04-03 Added command handling/state machine to enter sawtooth mode; still need to coordinate switching between phase0/phase1 registers for managing phase offset of accumulator
2020-04-06 Added QA test script for testing outgoing boards.
2020-04-08 Used STM32MXCube to generate TIM2 interrupt settings; wrote some code to toggle an IO as proof of GPIO life
2020-04-28 Deleted HW .sch-bak and .kicad_pcb-bak files. Added to .gitignore so future commits won't add them back.
2020-05-05 Added ToggleFreqRegister function to switch between freq0 and freq1
    Formatting cleanup
    Fixed a bug in SetFreq1Value - improperly masked to freq0 register
    [main.c]
2020-05-06 Added TogglePhaseReg() function to swap between phase0 and phase1 register values being applied to output. Added phasesel command to call TogglePhaseReg().
    [main.c]
2020-05-06 Finally fixed erroneous backspace/delete handling. The virtual com port console will now do proper backspacing!
    [main.c]
2020-05-06 Added waveform mode MOD_PSK to handle binary phase shift keying states.
    Added stub function SetSymbolRate() to set symbol interval for MOD_PSK.
    Will be filled in later with TIM2 settings to handle modulations.
    Added StopOutput() at the start of main(), before superloop, to reset DAC
    output on startup. Changed SetFreq0Value() and SetFreq1Value() to init to
    0x00000000.
    [main.c]
2020-05-07 Finished SetSymbolRate() function, which sets up TIM2 to fire an ISR at millisecond intervals.
    Finished StopModulation() function, which disables TIM2 by clearing the CEN
    bit.
    Binary phase shift keying example is complete. Needs a bit of refining on
    keying interval. Ex call: `mod_bpsk <freq> <symbol_int>`

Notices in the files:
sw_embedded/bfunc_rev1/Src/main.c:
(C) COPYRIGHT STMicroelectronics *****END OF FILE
